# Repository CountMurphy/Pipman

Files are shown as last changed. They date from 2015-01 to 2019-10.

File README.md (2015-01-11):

Pipman Propeller watch
======================

The Pipman is a GPS average intelligence (not dumb, but not quit smart like pebble) watch that runs on the propeller platform.  It boasts:

* 1 Gb internal memory (for saving calendar info and saving GPS coordinates)
* GPS (with time syncing abilities, can get local time anywhere in the world)
* Tilt Compensated Compass
* Temperature reader
* Color Screen
* Calendar
* USB support

Note: The current code is beta ( I'm not going to pretend all of it is clean. Some parts are rubbish.  You know it, I know it, lets move on) and hardware specific. It can be easily tweaked to suit your needs, but if you want to create the watch exactly as is the parts are as follows:

* A 4d systems oled-128-G1 (http://old.4dsystems.com.au/prod.php?id=78)  (the G2 should work too)
* Any NEMA Gps (though for the PCB designs I used this one: http://www.mouser.com/ProductDetail/4D-Systems/GPS-PA6B/?qs=0tg2fxsCAusQqyNQtvdH%252bA%3D%3D)
* The Honeywell hmc6343 (http://www.digikey.com/product-detail/en/HMC6343/342-1056-ND/1692480.  If you know how to tweak I2C code it wouldn't be hard to get any compass moduel to work)
* 5 way switch for navigation (http://www.adafruit.com/products/504)

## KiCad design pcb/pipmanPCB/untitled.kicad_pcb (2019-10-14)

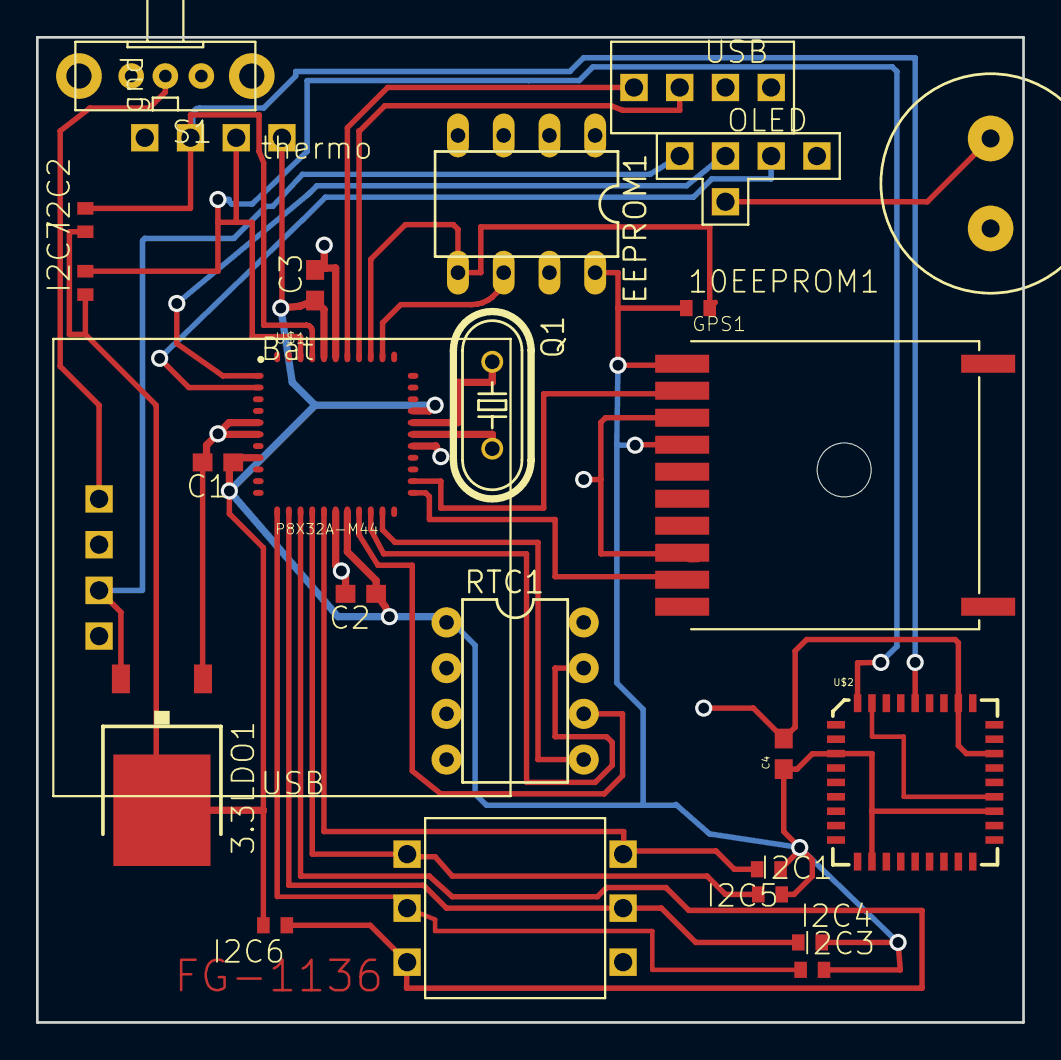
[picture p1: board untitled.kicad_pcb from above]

Board: 2 copper layers, 54.8 x 54.7 mm, 26 parts (0 on the bottom side), 26 nets.

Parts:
3.3LDO1: REG1117X; TO252
5WAYSWITCH1: 5-WAYSWITCH
10EEPROM1: R-US_R1005; R1005
C1, C2, C3: C-USC0603; C0603
C4: CAP0603; 0603
EEPROM1: DS1307; DIL08
GPS1: GPS_FGPMMOPA6B; FGPMMOPA6B
I2C1, I2C2, I2C3, I2C4, I2C5, I2C6, I2C7: R-US_R1005; R1005
LIPOCHARGER-BOOSTER1: SFLIPO
OLED_SCREEN1: 4DSCREEN
Q1: CRYSTALHC49S; HC49_S
RTC1: DS1302; DIL08-ROUND
S1: EG1213
SP1: SPEAKER_PS12; PS12
THERMO1: SFTEMP
U$1: P8X32A-M44
U$2: HMC6343A; LCC36
USB1: 4PINUSB

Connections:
+3V3: 3.3LDO1.3, 10EEPROM1.1, C1.1, C2.1, C3.1, C4.1, EEPROM1.8, GPS1.P$1, GPS1.P$4, I2C1.2, I2C2.1, I2C3.2, I2C4.2, I2C5.1, I2C6.2, I2C7.1, RTC1.1, THERMO1.VCC, U$1.8, U$1.18, U$1.30, U$1.40, U$2.3, U$2.11, U$2.21
+5V: 3.3LDO1.2, LIPOCHARGER-BOOSTER1.VCC, OLED_SCREEN1.5V
/SCL: I2C2.2, THERMO1.SCL, U$1.41, U$2.32
/SDA: I2C7.2, THERMO1.SDA, U$1.42, U$2.36
GND: 3.3LDO1.1, 5WAYSWITCH1.GND, C1.2, C2.2, C3.2, C4.2, EEPROM1.1, EEPROM1.2, EEPROM1.3, EEPROM1.4, EEPROM1.7, GPS1.P$3, GPS1.P$8, LIPOCHARGER-BOOSTER1.GND, OLED_SCREEN1.GND, RTC1.4, S1.1, SP1.P$2, THERMO1.GND, U$1.5, U$1.6, U$1.17, U$1.27, U$1.39, U$2.25, U$2.29, USB1.VSS
unnamed: 5WAYSWITCH1.BTN, I2C5.2, U$1.16
unnamed: 5WAYSWITCH1.D, I2C6.1, U$1.14
unnamed: 5WAYSWITCH1.L, I2C3.1, U$1.12
unnamed: 5WAYSWITCH1.R, I2C4.1, U$1.13
unnamed: 5WAYSWITCH1.U, I2C1.1, U$1.15
unnamed: 10EEPROM1.2, EEPROM1.5, U$1.36
unnamed: EEPROM1.6, U$1.35
unnamed: GPS1.P$2, U$1.24
unnamed: GPS1.P$9, U$1.23
unnamed: LIPOCHARGER-BOOSTER1.EN, S1.2
unnamed: OLED_SCREEN1.PEZ, SP1.P$1
unnamed: OLED_SCREEN1.RX, U$1.2
unnamed: OLED_SCREEN1.TX, U$1.1
unnamed: Q1.1, U$1.29
unnamed: Q1.2, U$1.28
unnamed: RTC1.5, U$1.21
unnamed: RTC1.6, U$1.19
unnamed: RTC1.7, U$1.20
unnamed: U$1.37, USB1.TX
unnamed: U$1.38, USB1.RX
unnamed: U$2.22, U$2.35

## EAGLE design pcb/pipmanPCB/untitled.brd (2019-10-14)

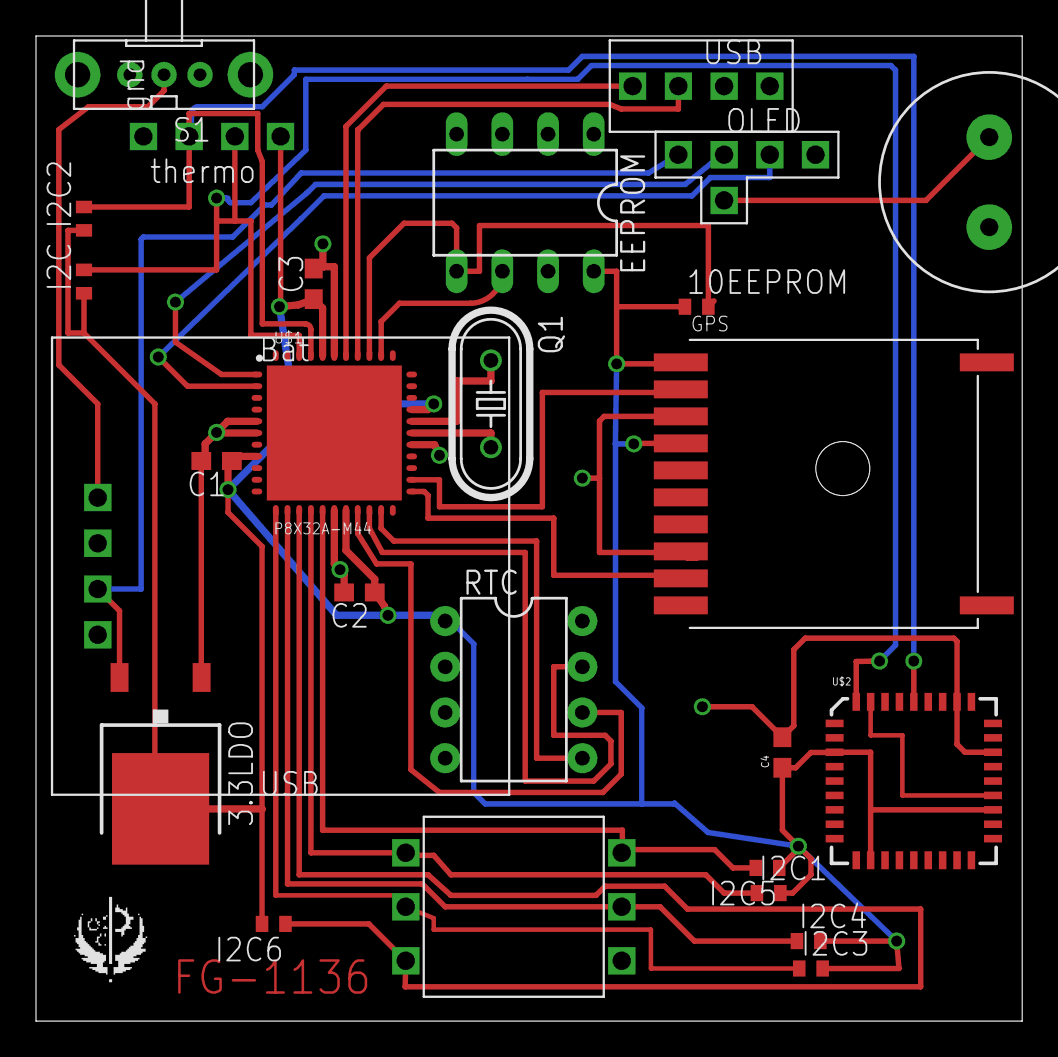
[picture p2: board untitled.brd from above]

Board: 2 copper layers, 54.8 x 54.7 mm, 26 parts (0 on the bottom side), 26 nets.

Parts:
3.3LDO: REG1117X; TO252
5WAYSWITCH: 5-WAYSWITCH
10EEPROM: R1005
C1, C2, C3: C0603
C4: 0603
EEPROM: DS1307; DIL08
GPS: FGPMMOPA6B
I2C, I2C1, I2C2, I2C3, I2C4, I2C5, I2C6: R1005
LIPOCHARGER-BOOSTER: SFLIPO
OLED_SCREEN: 4DSCREEN
Q1: HC49/S
RTC: DS1302; DIL08-ROUND
S1: EG1213
SP1: SPEAKER/PS12; PS12
THERMO: SFTEMP
U$1: P8X32A-M44
U$2: HMC6343A; LCC36
USB: 4PINUSB

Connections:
+3V3: 3.3LDO.3, 10EEPROM.1, C1.1, C2.1, C3.1, C4.1, EEPROM.8, GPS.P$1, GPS.P$4, I2C.1, I2C1.2, I2C2.1, I2C3.2, I2C4.2, I2C5.1, I2C6.2, RTC.1, THERMO.VCC, U$1.8, U$1.18, U$1.30, U$1.40, U$2.3, U$2.11, U$2.21
+5V: 3.3LDO.2, LIPOCHARGER-BOOSTER.VCC, OLED_SCREEN.5V
GND: 3.3LDO.1, 5WAYSWITCH.GND, C1.2, C2.2, C3.2, C4.2, EEPROM.1, EEPROM.2, EEPROM.3, EEPROM.4, EEPROM.7, GPS.P$3, GPS.P$8, LIPOCHARGER-BOOSTER.GND, OLED_SCREEN.GND, RTC.4, S1.1, SP1.P$2, THERMO.GND, U$1.5, U$1.6, U$1.17, U$1.27, U$1.39, U$2.25, U$2.29, USB.VSS
unnamed: Q1.2, U$1.28
unnamed: Q1.1, U$1.29
unnamed: GPS.P$9, U$1.23
unnamed: GPS.P$2, U$1.24
unnamed: RTC.5, U$1.21
unnamed: RTC.6, U$1.19
unnamed: U$1.38, USB.RX
unnamed: RTC.7, U$1.20
unnamed: U$1.37, USB.TX
unnamed: OLED_SCREEN.RX, U$1.2
unnamed: OLED_SCREEN.TX, U$1.1
unnamed: OLED_SCREEN.PEZ, SP1.P$1
unnamed: LIPOCHARGER-BOOSTER.EN, S1.2
unnamed: 5WAYSWITCH.U, I2C1.1, U$1.15
unnamed: 5WAYSWITCH.D, I2C6.1, U$1.14
unnamed: 5WAYSWITCH.L, I2C3.1, U$1.12
unnamed: 10EEPROM.2, EEPROM.5, U$1.36
unnamed: EEPROM.6, U$1.35
unnamed: 5WAYSWITCH.R, I2C4.1, U$1.13
unnamed: 5WAYSWITCH.BTN, I2C5.2, U$1.16
unnamed: U$2.22, U$2.35
SCL: I2C2.2, THERMO.SCL, U$1.41, U$2.32
SDA: I2C.2, THERMO.SDA, U$1.42, U$2.36

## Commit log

2012-11-24 added extra bool for track ball detection, renamed file
2013-05-06 added untested compass power modes. Will test when bst stops being a bitch
2013-06-09 Completed Screen driver
2013-06-17 Created Menu System
    Added temperature code. renamed compass.spin to sensors
2013-07-06 Finished Stop watch and timer
2013-08-13 Added spinner video for inital load, plays by frames for gps single and google
2013-10-13 Added GPS calibrate cancalation and removed redundant code
2013-10-13 Added Time to timer and fixed various timer bugs
2014-06-13 5way switch added to replace trackball
2014-06-13 think I really fixed the bug without ignoring edge case
2014-12-21 Reversed screen pins because I'm a noob and cant PCB
2018-07-17 added PCB in kicad
    [pipmanPCB.kicad_pcb, pipmanPCB.sch]
2019-10-14 screwed up last commit and commited empty files
    [pipmanPCB.kicad_pcb, pipmanPCB.sch, untitled.brd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]
